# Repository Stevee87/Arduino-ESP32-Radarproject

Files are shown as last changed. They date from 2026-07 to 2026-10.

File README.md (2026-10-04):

# Arduino ESP32 mmWave Radar Project
-------------------------------------------------------------------------------------------------------
Safety & disclaimer

This is a hobby project, shared as-is for anyone who wants to build their own version.
A few things to know before you do:

LiPo batteries: incorrect wiring, reverse polarity, or physical damage to a
LiPo cell can cause fire. Double-check polarity yourself before powering anything
on, use a charging module rated for the cell you're using, and never leave a
charging LiPo unattended.
RF hardware: the RD-03D and any radio modules in this project operate
according to their respective regulatory approvals (e.g. CE) for their intended
region — verify this applies to your location before use.
No warranty: this repository (firmware, wiring diagrams, enclosures, and this
README) is provided without any warranty, express or implied. Verify every
connection yourself before applying power — don't assume the diagrams here are
free of mistakes.
Use at your own risk: building and operating this project is entirely your
own responsibility. The author assumes no liability for damage, injury, or loss
resulting from building or using this project.

If you spot an error in the docs, wiring, or code, please open an issue — corrections
are welcome.
-------------------------------------------------------------------------------------------------------

A wireless 24GHz mmWave motion tracking system. A standalone radar node reports detected
targets over Wi-Fi to a separate display unit — so the radar and the screen don't have to
be in the same place.

v22 v21

## How it works

The radar module talks to an Arduino GIGA R1 via a Wi-Fi hotspot using a Seeed XIAO
ESP32-S3 as the transmitter. Because the link is wireless, the radar node can be placed
anywhere as a standalone motion detector, independent of where the display sits.

## Features

- Multi-target tracking (up to 3 people simultaneously, RD-03D built-in algorithm)
- 8 m rated detection range (expect 5–7 m indoors)
- Live radar-style visualization on the GIGA Display Shield
- Distance-reactive tracker sound (passive piezo buzzer, tempo and pitch scale with
  the closest target's distance) — mute toggle built into the touchscreen
- LED battery level indicators on both battery packs
- Battery powered on both ends, USB-C rechargeable

## Known limitations

- The RD-03D is a **Doppler-based** radar — it only detects *moving* targets. People
  standing still are not detected.
- Works best stationary. It can detect people while the sensor itself is moving, but
  accuracy drops significantly.
- Can detect motion through thin doors/walls, but range is severely reduced — a
  consequence of 24GHz wave physics, not a firmware limitation.
- **Boot order matters**: always power on the GIGA R1 first and let it fully initialize
  before powering the radar node. Otherwise the Wi-Fi connection will not be established.

## Bill of materials

| Qty | Part |
|---|---|
| 1 | Arduino GIGA R1 |
| 1 | Arduino GIGA Display Shield |
| 1 | Seeed Studio XIAO ESP32-S3 |
| 1 | RD-03D radar module (Ai-Thinker) |
| 2 | Toggle switch |
| 2 | MT3608 step-up converter |
| 1 | 3.7V LiPo, 1160100 (≥5000mAh) — GIGA side |
| 1 | 3.7V LiPo, 602560 (~1300mAh) — radar side |
| 2 | BW4056 USB-C charging module |
| 1 | Passive piezo buzzer module (VCC/GND/Signal, tracker sound, GIGA side) |
| 2 | Mini Battery Level Indicator, 1S Li-ion — [ElectroPeak BAT-03-086](https://electropeak.com/mini-battery-level-indicator-1s-li-ion), one per LiPo |
| 4 | Magnets |
| — | Wires, M3 heat-set inserts, M3x10mm screws, 3D printer, glue, tape |

## Wiring

circuit diagram v2

**Power (GIGA side):** LiPo (5000mAh) → BW4056 charging module → toggle switch →
step-up converter set to 7–7.5V → GIGA `VIN`. Do not set it to 6V: that is the
bottom of the GIGA's 6–24V input range and the board browns out as the cell
discharges. Alternatively feed 5V into the GIGA's USB-C port from a 5V boost or
power-bank module and skip `VIN` altogether.

**Power (radar side):** LiPo (1300mAh) → BW4056 charging module → toggle switch →
XIAO `BAT+`/`BAT-` (on the back of the board), **directly**. A second branch from
the switched battery rail feeds the step-up converter set to 5V, which powers
**only the RD-03D**.

Never connect the 5V step-up output to `BAT+`: the BAT pads are the cell
terminals of the XIAO's 1S charger (4.2V maximum), and a cell behind a boost
converter cannot be charged by the XIAO. With the cell on the BAT pads the XIAO's
USB-C also charges it (100mA, slow); never charge through the BW4056 and the XIAO
at the same time.

### XIAO ESP32-S3 ↔ RD-03D (transmitter)

| RD-03D pin | XIAO pin | Notes |
|---|---|---|
| TX | D0 (GPIO1) | UART1 RX |
| RX | D1 (GPIO2) | UART1 TX |
| BAT+ | — | 3,7 V from the TP4056 |
| GND | GND | |

CAUTION: When charging the battery, set the POWER button to OFF. The same applies when the microcontroller is connected via USB-C. 

Baud rate: 256000. Do **not** use D6/D7 (GPIO43/44) — reserved for USB-Serial (UART0).

Antennas: neither the XIAO ESP32-S3 nor the GIGA R1 WiFi has an on-board antenna.
Plug in the u.FL antenna that ships with each board, and route the XIAO's away from
the LiPo and the magnets, or the Wi-Fi link will only work over a few metres.

### Wi-Fi link
### Arduino Giga R1 ↔ (receiver)
| | Value |
|---|---|
| Mode | GIGA R1 hosts an access point, XIAO connects as client |
| SSID | `RadarNet` |
| Password | `radar12345` |
| UDP port | 4210 |
| GIGA IP | 192.168.3.1 (default of the Arduino Mbed core; the sketch never sets an address and the XIAO uses the DHCP gateway, so nothing depends on this value) |

### Tracker sound (buzzer)

| Buzzer | GIGA R1 |
|---|---|
| VCC | 3V3 (GIGA pins are not 5V tolerant and many 3-pin buzzer modules pull the signal line up to VCC) |
| Signal (I/O) | D9 |
| GND | GND |

Must be a **passive** piezo buzzer, not active — an active buzzer has its own
oscillator and only turns on/off, ignoring the frequency argument the code sends it.

Behavior: silent when no target is detected. Once a target appears, it emits short
(70ms) pings whose repeat rate and pitch both scale with the distance to the closest
detected target — pings speed up and rise in pitch as someone gets closer (900ms /
700Hz at ~8m down to 120ms / 1800Hz at ≤30cm). A mute toggle button is drawn directly
on the touchscreen; tapping it silences the buzzer without affecting the radar
visualization.

### Battery level indicators

Two [ElectroPeak Mini Battery Level Indicator (1S Li-ion)](https://electropeak.com/mini-battery-level-indicator-1s-li-ion)
boards, one per LiPo pack. These are standalone analog modules (built-in comparator,
±1% accuracy) — no microcontroller pin or firmware involved. Wire each board directly
across its own battery's `+`/`-` terminals (in parallel with the existing BW4056 /
step-up wiring, not in series):

| Indicator LEDs lit | Charge level |
|---|---|
| 4 | 100% |
| 3 | 75% |
| 2 | 50% |
| 1 | 25% |

Board size is tiny (5 × 9.5mm) — tuck it wherever it fits in the enclosure near the
battery leads.

## Firmware

Open `Firmware/rd03d_xiao_s3_transmitter/rd03d_xiao_s3_transmitter.ino` and flash it to
the XIAO ESP32-S3, then open `Firmware/rd03d_giga_receiver/rd03d_giga_receiver.ino` and
flash it to the GIGA R1 — both via Arduino IDE.

**Board packages:**
- `esp32` by Espressif (3.x) — board "XIAO_ESP32S3", *USB CDC On Boot: Enabled*
- `Arduino Mbed OS GIGA Boards` (4.x) — board "Arduino GIGA R1 WiFi". If the GIGA has never
  run Wi-Fi, flash *File → Examples → STM32H747_System → WiFiFirmwareUpdater* once first.

**Required libraries:**
- `Arduino_GigaDisplay_GFX` (GIGA — display rendering; depends on `Adafruit GFX Library`)
- `Arduino_GigaDisplayTouch` (GIGA — touch input)
- `WiFi` / `WiFiUdp` (both boards, built into their respective cores)

## Enclosures

Four 3D-printable parts are included in `CAD files/` (binary STL; bounding boxes
measured from the files):

| File | Bounding box (mm) | Part |
|---|---|---|
| `CAD files/body display.stl` | 34 × 105 × 113 | display body (GIGA + shield + 1160100 LiPo) |
| `CAD files/top display.stl` | 8 × 85 × 111 | display lid |
| `CAD files/top radarmodule.stl` | 47 × 31 × 87 | radar node body |
| `CAD files/bottom radarmodule.stl` | 47 × 6 × 67 | radar node base plate |

## Build photos (older ones, without the battery indicator and buzzer)

building pictures

## License

MIT — see [LICENSE](LICENSE).

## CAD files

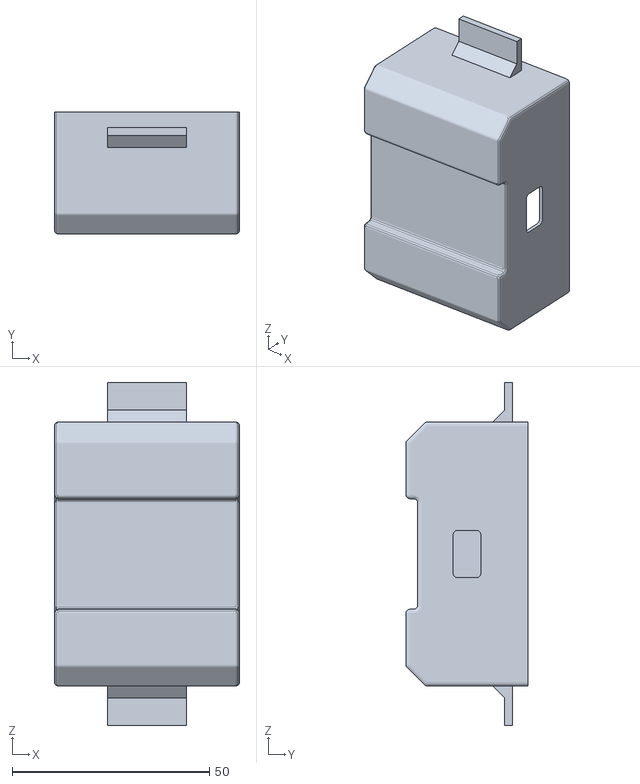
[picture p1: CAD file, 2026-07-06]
CAD files/top radarmodule.stl
47.0 x 31.0 x 87.0

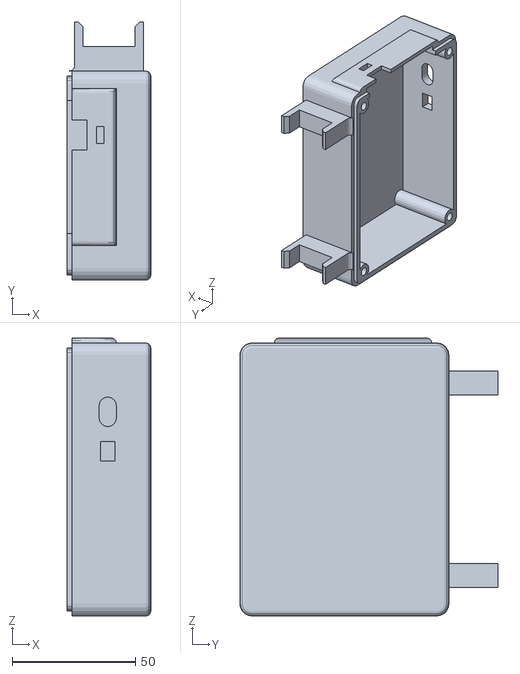
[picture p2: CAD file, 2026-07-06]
CAD files/body display.stl
34.0 x 105.0 x 113.0

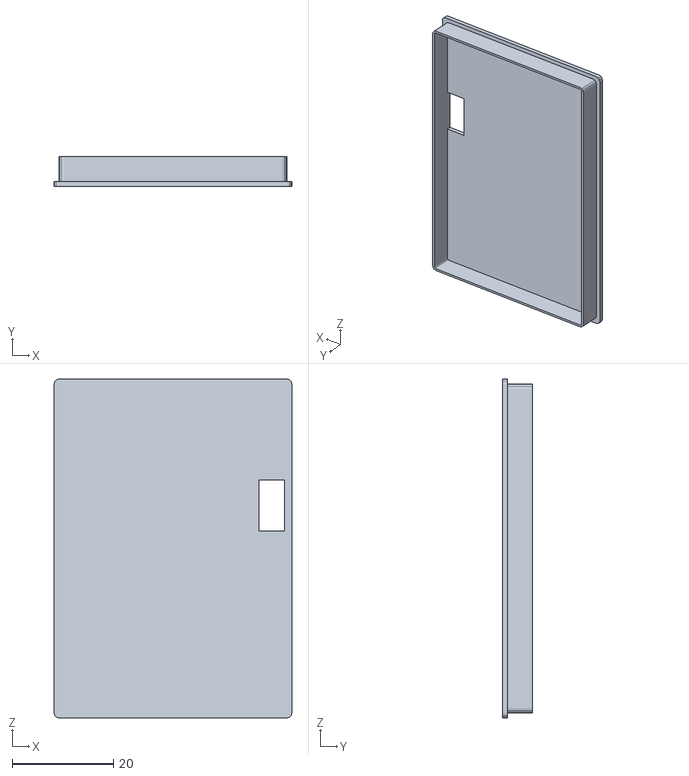
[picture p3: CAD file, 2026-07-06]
CAD files/bottom radarmodule.stl
47.0 x 6.00 x 67.0

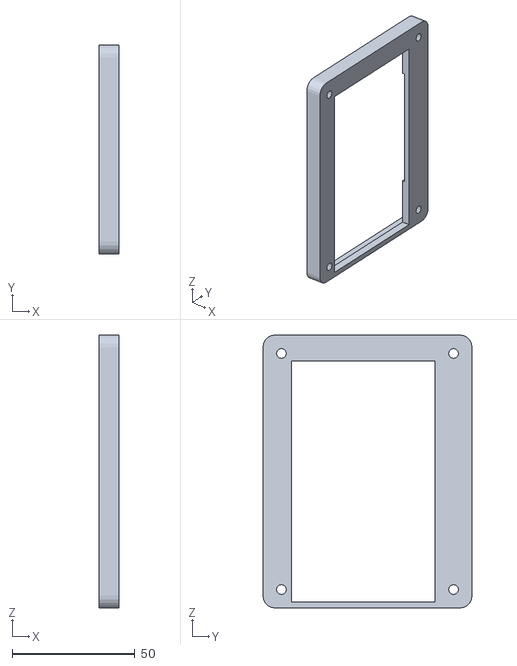
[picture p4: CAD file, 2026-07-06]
CAD files/top display.stl
8.00 x 85.0 x 111.0

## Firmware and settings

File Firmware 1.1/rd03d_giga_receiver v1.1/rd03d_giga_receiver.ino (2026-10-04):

/*
 * RD-03D Radar Display — Arduino Giga R1
 * Empfängt UDP-Pakete vom Single-Sensor-Sender und zeigt bis zu 3 Targets
 * auf dem Display (ein RD-03D, 120° Sichtfeld).
 *
 * NETZWERK:
 *   Giga R1 ist Hotspot: SSID "RadarNet", PW "radar12345"
 *   Eigene IP: 192.168.3.1 (Standard des Arduino-Mbed-Cores; der XIAO nutzt die Gateway-IP)
 *   UDP Port: 4210
 */

#include <WiFi.h>
#include <WiFiUdp.h>
#include "Arduino_GigaDisplay_GFX.h"
#include "Arduino_GigaDisplayTouch.h"

// ── Netzwerk ──
const char*    AP_SSID = "RadarNet";
const char*    AP_PASS = "radar12345";
const uint16_t UDP_PORT = 4210;

// ── Display ──
#define SCREEN_W    800
#define SCREEN_H    480
#define RADAR_CX    400
#define RADAR_CY    480
#define RADAR_R     440
#define MAX_DIST_MM 8000.0f
#define SECTOR_HALF 60.0f
#define MAX_TARGETS 3
#define MOVE_THRESH_MM 15.0f

// ── Ein Sensor, 120° FOV, zentriert auf die Gerätefront (0°) ──
#define NUM_SECTORS 1
const float SECTOR_CENTERS[NUM_SECTORS] = {0.0f};

// ── Buzzer (Tracker-Sound) ──
#define BUZZER_PIN     9      // passiver Piezo-Buzzer, KEIN aktiver Buzzer!

// Jeder Ping besteht aus 2 Stufen: kurzer heller "Klick" (Attack) direkt
// gefolgt vom eigentlichen Ton — kommt dem hellen, sonarartigen Charakter
// des Vorbilds näher als ein einzelner flacher Ton.
// Jeder Ping ist ein kurzer 3-stufiger AUFWÄRTS-Sweep (tief -> mittel ->
// Zielfrequenz), statt eines einzelnen flachen Tons — klingt nach einem
// ansteigenden Sonar-Ping statt einem Klick.
const uint16_t PING_STAGE1_MS = 26;
const uint16_t PING_STAGE2_MS = 24;
const uint16_t PING_STAGE3_MS = 30;
#define BEEP_DUR_MS  (PING_STAGE1_MS + PING_STAGE2_MS + PING_STAGE3_MS)   // Gesamtlänge eines Pings

const float    BEEP_DIST_MIN      = 300.0f;   // mm — ab hier schnellster/höchster Ping
const float    BEEP_DIST_MAX      = 8000.0f;  // mm — ab hier langsamster/tiefster Ping
const uint16_t BEEP_INTERVAL_MIN  = 120;      // ms Pause zwischen Pings bei minimaler Distanz
const uint16_t BEEP_INTERVAL_MAX  = 900;      // ms Pause zwischen Pings bei maximaler Distanz
const uint16_t BEEP_FREQ_MIN      = 700;      // Hz — Tonhöhe weit weg (Kompromiss: lauter, aber unterhalb des schrillen Bereichs)
const uint16_t BEEP_FREQ_MAX      = 1400;     // Hz — Tonhöhe nah dran

// ── Mute-Button (Touch) ──
#define BTN_X 660
#define BTN_Y 400
#define BTN_W 130
#define BTN_H 40
bool buzzerMuted = false;

// ── Range-HUD-Position (Basis der Radar-Kuppel, überdeckt Ursprung) ──
#define RANGE_HUD_W 140
#define RANGE_HUD_H 40
#define RANGE_HUD_X (RADAR_CX - RANGE_HUD_W/2)
#define RANGE_HUD_Y (RADAR_CY - RANGE_HUD_H)

// ── Farben ──
#define C_BG    0x0000
#define C_GREEN 0x07E0
#define C_GDIM  0x02E0
#define C_RED   0xF800
#define C_AMBER 0xFD20
#define C_CYAN  0x07FF
#define C_WHITE 0xFFFF

GigaDisplay_GFX          display;
Arduino_GigaDisplayTouch touch;
WiFiUDP                  udp;

struct Target {
  int16_t x;
  int16_t y;
  int16_t spd;
  uint8_t valid;
};

struct __attribute__((packed)) UdpPacket {
  uint32_t magic;
  uint32_t frameCount;
  Target   targets[MAX_TARGETS];
};

struct DisplayTarget {
  float x, y, spd;
  bool  valid;
};

struct DotState {
  int16_t cx, cy, bx, by, bw, bh;
  bool active;
};

DisplayTarget targets[MAX_TARGETS];
DisplayTarget lastDrawn[MAX_TARGETS];
DotState      dots[MAX_TARGETS];

// ── Ghost-Filter: Ziel, das sich 2s lang nicht (spürbar) bewegt, gilt als ──
// Störung/Geisterziel (der RD-03D erkennt stehende Personen ohnehin nicht
// zuverlässig — ein "Ziel", das sich gar nicht bewegt, ist verdächtig) und
// wird ausgeblendet, bis es sich wieder über MOVE_THRESH_MM hinaus bewegt.
DisplayTarget prevRaw[MAX_TARGETS];       // Ground-Truth letzte Rohposition
uint32_t      stillSinceMs[MAX_TARGETS];  // Zeitpunkt der letzten echten Bewegung
const uint32_t STILL_TIMEOUT_MS = 2000;

uint32_t frameCount = 0;
uint32_t lastPacketMs = 0;
bool     txConnected = false;

// Buzzer-Status
uint32_t lastBeepMs   = 0;
bool     beepActive   = false;
uint8_t  chirpStage      = 0;   // 0=idle, 1/2/3=Sweep-Stufen (tief->mittel->Ziel)
uint32_t chirpStageStart = 0;
uint16_t chirpMainFreq   = 0;

// Hintergrund-Puls: läuft konstant, solange das Gerät an ist — unabhängig
// davon, ob ein Ziel erkannt wird. Signalisiert "Radar läuft/scannt".
const uint16_t PULSE_FREQ        = 300;   // Hz, Original-Wert
const uint16_t PULSE_DUR_MS      = 40;    // kurz, damit es nicht aufdringlich wird
const uint32_t PULSE_INTERVAL_MS = 1800;  // Pause zwischen zwei Pulsen
uint32_t lastPulseMs  = 0;
bool     pulseActive  = false;
uint32_t pulseStartMs = 0;

// ── UDP empfangen ──
// Wartende Datagramme abholen und das letzte gültige Paket anzeigen.
void receiveUdp() {
  static uint32_t lastDebug = 0;
  static uint32_t rxCount   = 0;
  UdpPacket pkt = {};
  bool gotPacket = false;
  int sz;
  while ((sz = udp.parsePacket()) > 0) {
    if (sz < (int)sizeof(UdpPacket)) continue;
    UdpPacket tmp = {};
    if (udp.read((uint8_t*)&tmp, sizeof(tmp)) != (int)sizeof(tmp)) continue;
    if (tmp.magic != 0xD03DA7A) continue;
    pkt = tmp;
    gotPacket = true;
    rxCount++;
  }
  if (millis() - lastDebug > 2000) {
    lastDebug = millis();
    Serial.print("UDP Pakete gesamt="); Serial.println(rxCount);
  }
  if (!gotPacket) return;

  frameCount = pkt.frameCount;
  lastPacketMs = millis();
  txConnected = true;

  for (int i = 0; i < MAX_TARGETS; i++) {
    if (pkt.targets[i].valid) {
      targets[i].x     = (float)pkt.targets[i].x;
      targets[i].y     = (float)pkt.targets[i].y;
      targets[i].spd   = (float)abs(pkt.targets[i].spd);
      targets[i].valid = true;
    } else {
      targets[i].valid = false;
    }
  }
}

// ── Maßstab ──
float distToR(float d) {
  if (d <= 0)       return 0;
  if (d <= 2000.0f) return (d/2000.0f)                          * 0.50f * RADAR_R;
  if (d <= 4000.0f) return (0.50f+(d-2000.0f)/2000.0f*0.25f)   * RADAR_R;
  if (d <= 6000.0f) return (0.75f+(d-4000.0f)/2000.0f*0.15f)   * RADAR_R;
  return              (0.90f+(d-6000.0f)/2000.0f*0.10f)         * RADAR_R;
}

void targetToPixel(float x, float y, int16_t &px, int16_t &py) {
  float dist  = sqrtf(x*x + y*y);
  float angle = atan2f(x, y) * 180.0f / PI;
  float r     = distToR(dist);
  float rad   = (angle - 90.0f) * PI / 180.0f;
  px = RADAR_CX + (int16_t)(r * cosf(rad));
  py = RADAR_CY + (int16_t)(r * sinf(rad));
}

// ── Hintergrund-Region neu zeichnen ──
void redrawBg(int16_t rx1, int16_t ry1, int16_t rw, int16_t rh) {
  int16_t rx2 = rx1+rw-1, ry2 = ry1+rh-1;
  if (rx1<0) rx1=0; if (ry1<0) ry1=0;
  if (rx2>=SCREEN_W) rx2=SCREEN_W-1;
  if (ry2>=SCREEN_H) ry2=SCREEN_H-1;
  if (rx1>rx2||ry1>ry2) return;
  display.fillRect(rx1,ry1,rx2-rx1+1,ry2-ry1+1,C_BG);
  for (int s=0; s<NUM_SECTORS; s++) {
    float c = SECTOR_CENTERS[s];
    float rd[]={1000,2000,3000,4000,5000,6000,7000,8000};
    uint16_t rc[]={C_GREEN,0x00C0,0x00C0,C_GDIM,0x00C0,0x00C0,0x00C0,C_GREEN};
    for (int ri=0; ri<8; ri++) {
      float r=distToR(rd[ri]);
      for (float a=c-SECTOR_HALF; a<=c+SECTOR_HALF; a+=0.5f) {
        float rad=(a-90.0f)*PI/180.0f;
        int16_t px=RADAR_CX+(int16_t)(r*cosf(rad)), py=RADAR_CY+(int16_t)(r*sinf(rad));
        if (px>=rx1&&px<=rx2&&py>=ry1&&py<=ry2) display.drawPixel(px,py,rc[ri]);
      }
    }
    int degs[]={-60,-30,0,30,60};
    for (int i=0; i<5; i++) {
      float rad=(c+degs[i]-90.0f)*PI/180.0f;
      for (float r=0; r<=RADAR_R; r+=1.5f) {
        int16_t px=RADAR_CX+(int16_t)(r*cosf(rad)), py=RADAR_CY+(int16_t)(r*sinf(rad));
        if (px>=rx1&&px<=rx2&&py>=ry1&&py<=ry2) display.drawPixel(px,py,degs[i]==0?C_GDIM:0x0200);
      }
    }
  }
  if (RADAR_CX>=rx1&&RADAR_CX<=rx2&&RADAR_CY>=ry1&&RADAR_CY<=ry2) {
    display.fillCircle(RADAR_CX,RADAR_CY,5,C_GREEN);
    display.drawCircle(RADAR_CX,RADAR_CY,9,C_GDIM);
  }
}

// ── Aktive Dots neu zeichnen, die von einer Region betroffen sein könnten ──
// (z.B. nachdem redrawBg() über sie drübergemalt hat)
void redrawDotsInRegion(int16_t rx1, int16_t ry1, int16_t rw, int16_t rh) {
  int16_t rx2 = rx1 + rw - 1, ry2 = ry1 + rh - 1;
  for (int i = 0; i < MAX_TARGETS; i++) {
    if (!dots[i].active) continue;
    if (dots[i].bx <= rx2 && dots[i].bx + dots[i].bw - 1 >= rx1 &&
        dots[i].by <= ry2 && dots[i].by + dots[i].bh - 1 >= ry1) {
      drawDot(i);
    }
  }
}

// ── Sichtbarer Sonar-Ping: ein Ring, der vom Ursprung nach außen läuft ──
void drawPingRing(float r, uint16_t color) {
  for (int s = 0; s < NUM_SECTORS; s++) {
    float c = SECTOR_CENTERS[s];
    for (float a = c - SECTOR_HALF; a <= c + SECTOR_HALF; a += 0.5f) {
      float rad = (a - 90.0f) * PI / 180.0f;
      int16_t px = RADAR_CX + (int16_t)(r * cosf(rad));
      int16_t py = RADAR_CY + (int16_t)(r * sinf(rad));
      if (px < 0 || px >= SCREEN_W || py < 0 || py >= SCREEN_H) continue;
      // Range-HUD-Bar an der Basis aussparen, sonst überschreibt der
      // durchlaufende Ping kurzzeitig die Zahl
      if (px >= RANGE_HUD_X && px <= RANGE_HUD_X + RANGE_HUD_W &&
          py >= RANGE_HUD_Y && py <= RANGE_HUD_Y + RANGE_HUD_H) continue;
      display.drawPixel(px, py, color);
    }
  }
}

// Hintergrundfarbe, die an Radius r "eigentlich" stehen würde (feste
// Range-Ring-Farbe falls Treffer, sonst normale BG-Farbe) — für das
// günstige Zurückschreiben beim Löschen des Ping-Rings.
uint16_t bgColorAtRadius(float r) {
  float rangeMm[]  = {1000,2000,3000,4000,5000,6000,7000,8000};
  uint16_t rangeCol[] = {C_GREEN,0x00C0,0x00C0,C_GDIM,0x00C0,0x00C0,0x00C0,C_GREEN};
  for (int k = 0; k < 8; k++) {
    if (fabsf(distToR(rangeMm[k]) - r) < 1.0f) return rangeCol[k];
  }
  return C_BG;
}

// Bounding-Box eines Rings bei Radius r über alle Sektoren hinweg — NUR
// zur groben Prüfung, ob ein Dot vom Ring gekreuzt wird, NICHT für einen
// vollflächigen Redraw (der wäre bei einem 120°-Bogen riesig und würde
// weit entfernte UI-Elemente wie Info-Box/Button mit überschreiben).
void ringBoundingBox(float r, int16_t &bx1, int16_t &by1, int16_t &bx2, int16_t &by2) {
  float minA = SECTOR_CENTERS[0] - SECTOR_HALF;
  float maxA = SECTOR_CENTERS[NUM_SECTORS-1] + SECTOR_HALF;
  bx1 = 32000; by1 = 32000; bx2 = -32000; by2 = -32000;
  for (float a = minA; a <= maxA; a += 2.0f) {
    float rad = (a - 90.0f) * PI / 180.0f;
    int16_t px = RADAR_CX + (int16_t)(r * cosf(rad));
    int16_t py = RADAR_CY + (int16_t)(r * sinf(rad));
    if (px < bx1) bx1 = px; if (px > bx2) bx2 = px;
    if (py < by1) by1 = py; if (py > by2) by2 = py;
  }
  bx1 -= 2; by1 -= 2; bx2 += 2; by2 += 2;
}

// Sweep-Dauer bewusst etwas kürzer als PULSE_INTERVAL_MS (Puls löst den
// Ring aus, siehe triggerPing() in updateBackgroundPulse) — Ring läuft
// exakt im Takt des Sounds, kein eigener Pause-Timer mehr nötig.
const float    PING_SPEED_PX_MS = 440.0f / (PULSE_INTERVAL_MS - 200.0f);
const uint32_t PING_FRAME_MS    = 40;                // ~25 FPS für die Animation

float    pingRadius        = 0;
float    pingPrevRadius    = -1;
bool     pingRunning        = false;
uint32_t lastPingFrameMs   = 0;

// Wird vom Sound-Puls aufgerufen — startet den Ring exakt im gleichen Moment
void triggerPing() {
  pingRadius   = 0;
  pingRunning  = true;
}

void updatePing() {
  uint32_t now = millis();
  if (now - lastPingFrameMs < PING_FRAME_MS) return;
  float dt = (float)(now - lastPingFrameMs);
  lastPingFrameMs = now;

  // Alten Ring löschen: NUR die exakt gleichen Pixel zurückschreiben, die
  // gezeichnet wurden (billig, ~240 Punkte) statt eine teure
  // Bounding-Box-Fläche über redrawBg() neu zu zeichnen (das kostet pro
  // Aufruf zehntausende Iterationen und malt dabei über Info-Box/Button).
  if (pingPrevRadius >= 0) {
    drawPingRing(pingPrevRadius, bgColorAtRadius(pingPrevRadius));
    int16_t bx1, by1, bx2, by2;
    ringBoundingBox(pingPrevRadius, bx1, by1, bx2, by2);
    redrawDotsInRegion(bx1, by1, bx2 - bx1 + 1, by2 - by1 + 1);
    pingPrevRadius = -1;
  }

  if (!pingRunning) return;

  drawPingRing(pingRadius, C_GREEN);
  pingPrevRadius = pingRadius;
  pingRadius += PING_SPEED_PX_MS * dt;

  if (pingRadius > RADAR_R) {
    pingRunning = false;
  }
}

// ── Hintergrund initial ──
void drawBackground() {
  display.fillScreen(C_BG);
  for (int s=0; s<NUM_SECTORS; s++) {
    float c = SECTOR_CENTERS[s];

    float rd[]={1000,2000,3000,4000,5000,6000,7000,8000};
    uint16_t rc[]={C_GREEN,0x00C0,0x00C0,C_GDIM,0x00C0,0x00C0,0x00C0,C_GREEN};
    for (int ri=0; ri<8; ri++) {
      float r=distToR(rd[ri]);
      for (float a=c-SECTOR_HALF; a<=c+SECTOR_HALF; a+=0.5f) {
        float rad=(a-90.0f)*PI/180.0f;
        int16_t px=RADAR_CX+(int16_t)(r*cosf(rad)), py=RADAR_CY+(int16_t)(r*sinf(rad));
        if (px>=0&&px<SCREEN_W&&py>=0&&py<SCREEN_H) display.drawPixel(px,py,rc[ri]);
      }
      // Distanz-Label nur an der äußeren rechten Kante von Sektor 0 setzen,
      // sonst würden sich die Labels beider Sektoren an der gemeinsamen
      // Nahtstelle (60°) überlappen.
      if (s==0) {
        display.setTextColor(ri==0||ri==7?C_GREEN:0x0380); display.setTextSize(1);
        char buf[8]; sprintf(buf,"%.0fm",rd[ri]/1000.0f);
        float rR=(c+SECTOR_HALF+6.0f-90.0f)*PI/180.0f;  // etwas außerhalb der Randlinie, nicht mehr drauf
        int16_t lx=RADAR_CX+(int16_t)((r+4)*cosf(rR))+4, ly=RADAR_CY+(int16_t)((r+4)*sinf(rR))-4;
        if (lx>=0&&lx<SCREEN_W&&ly>=0&&ly<SCREEN_H) { display.setCursor(lx,ly); display.print(buf); }
      }
    }

    float radL=(c-SECTOR_HALF-90.0f)*PI/180.0f, radR=(c+SECTOR_HALF-90.0f)*PI/180.0f;
    for (int off=-1; off<=1; off++) {
      display.drawLine(RADAR_CX+off,RADAR_CY,RADAR_CX+off+(int16_t)(RADAR_R*cosf(radL)),RADAR_CY+(int16_t)(RADAR_R*sinf(radL)),C_GREEN);
      display.drawLine(RADAR_CX+off,RADAR_CY,RADAR_CX+off+(int16_t)(RADAR_R*cosf(radR)),RADAR_CY+(int16_t)(RADAR_R*sinf(radR)),C_GREEN);
    }

    int degs[]={-60,-30,0,30,60};
    for (int i=0; i<5; i++) {
      float rad=(c+degs[i]-90.0f)*PI/180.0f;
      display.drawLine(RADAR_CX,RADAR_CY,RADAR_CX+(int16_t)(RADAR_R*cosf(rad)),RADAR_CY+(int16_t)(RADAR_R*sinf(rad)),degs[i]==0?C_GDIM:0x0260);
      char buf[5]; sprintf(buf,"%d",(int)(c+degs[i]));
      float lr=RADAR_R+14.0f;
      int16_t lx=RADAR_CX+(int16_t)(lr*cosf(rad))-6, ly=RADAR_CY+(int16_t)(lr*sinf(rad))-4;
      if (lx>=0&&lx<SCREEN_W&&ly>=0) { display.setTextColor(degs[i]==0?C_GREEN:0x0380); display.setTextSize(1); display.setCursor(lx,ly); display.print(buf); }
    }
  }
  display.fillCircle(RADAR_CX,RADAR_CY,5,C_GREEN);
  display.drawCircle(RADAR_CX,RADAR_CY,9,C_GDIM);
  // Info-Box
  display.fillRect(670,0,130,70,0x0820);
  display.setTextColor(C_GDIM); display.setTextSize(1);
  display.setCursor(675, 4); display.print("RD-03D 24GHz");
  display.setCursor(675,14); display.print("3T 8m 120deg");
  display.setCursor(675,24); display.print("AP: RadarNet");
}

// 3 Targets vom einzigen Sensor
static const uint16_t DOT_COLS[MAX_TARGETS] = {C_RED, C_AMBER, C_CYAN};

void eraseDot(int i) {
  if (!dots[i].active) return;
  redrawBg(dots[i].bx, dots[i].by, dots[i].bw, dots[i].bh);
  dots[i].active = false;
}

void drawDot(int i) {
  int16_t tx, ty;
  targetToPixel(targets[i].x, targets[i].y, tx, ty);
  uint16_t col = DOT_COLS[i];
  int16_t bx=tx-22, by=ty-22, bw=44, bh=44;
  display.drawCircle(tx,ty,18,col);
  display.drawCircle(tx,ty,11,col);
  display.fillCircle(tx,ty, 5,col);
  dots[i]      = {tx,ty,bx,by,bw,bh,true};
  lastDrawn[i] = targets[i];
}

bool staleNow[MAX_TARGETS];

// ── Distanz-Labels fest am Ursprung statt am beweglichen Punkt ──
// Fester, umrandeter Kasten unter dem Mute-Button — nicht mehr am
// beweglichen Ursprung, sondern in der gleichen UI-Spalte wie Info-Box
// und Button. Malt sich komplett selbst neu (eigener Hintergrund-Fill),
// braucht kein redrawBg() und kann daher auch nichts anderes überschreiben.
#define TGT_BOX_X   10
#define TGT_BOX_Y   400
#define TGT_BOX_W   130
#define TGT_BOX_LINE_H 14
#define TGT_BOX_H   (MAX_TARGETS * TGT_BOX_LINE_H + 16)
const uint32_t TGT_BOX_INTERVAL_MS = 150;
uint32_t lastTgtBoxMs = 0;

void drawTargetBox() {
  display.fillRect(TGT_BOX_X, TGT_BOX_Y, TGT_BOX_W, TGT_BOX_H, 0x0820);
  display.drawRect(TGT_BOX_X, TGT_BOX_Y, TGT_BOX_W, TGT_BOX_H, C_GDIM);
  display.setTextColor(C_GDIM); display.setTextSize(1);
  display.setCursor(TGT_BOX_X + 6, TGT_BOX_Y + 4);
  display.print("TARGETS");

  display.setTextSize(1);
  int line = 0;
  for (int i = 0; i < MAX_TARGETS; i++) {
    if (!targets[i].valid || staleNow[i]) continue;
    float dist = sqrtf(targets[i].x*targets[i].x + targets[i].y*targets[i].y);
    char buf[20];
    if (targets[i].spd > 2.0f) sprintf(buf, "T%d %.2fm %dcm/s", i+1, dist/1000.0f, (int)targets[i].spd);
    else                       sprintf(buf, "T%d %.2fm", i+1, dist/1000.0f);
    display.setTextColor(DOT_COLS[i]);
    display.setCursor(TGT_BOX_X + 6, TGT_BOX_Y + 16 + line * TGT_BOX_LINE_H);
    display.print(buf);
    line++;
  }
}

void updateTargetBox() {
  if (millis() - lastTgtBoxMs < TGT_BOX_INTERVAL_MS) return;
  lastTgtBoxMs = millis();
  drawTargetBox();
}

// ── Großer Range-Readout an der Basis der Radar-Kuppel (Ursprungspunkt) ──
// Referenz: Tracker-UI mit großer Zahl direkt unter der Scope-Grafik.
// Bei unserem Layout sitzt der Ursprung am unteren Bildschirmrand, daher
// wird die Bar dort platziert statt "unter" dem Bogen — überdeckt den
// Ursprungsmarker bewusst, genau wie im Referenzbild der Fokuspunkt der
// Kuppel durch die Zahl ersetzt wird.
const uint32_t RANGE_HUD_INTERVAL_MS = 150;
uint32_t lastRangeHudMs = 0;

void drawRangeHud() {
  display.fillRect(RANGE_HUD_X, RANGE_HUD_Y, RANGE_HUD_W, RANGE_HUD_H, 0x0000);
  display.drawRect(RANGE_HUD_X, RANGE_HUD_Y, RANGE_HUD_W, RANGE_HUD_H, C_GDIM);

  float dist = closestTargetDistMm();
  display.setTextSize(3);
  char buf[10];
  if (dist >= 0) {
    display.setTextColor(C_RED);
    sprintf(buf, "%.2fm", dist/1000.0f);
  } else {
    display.setTextColor(C_GDIM);
    sprintf(buf, "---");
  }
  int16_t textW = strlen(buf) * 18;  // grobe Breitenschätzung bei textSize(3)
  display.setCursor(RADAR_CX - textW/2, RANGE_HUD_Y + (RANGE_HUD_H - 24) / 2);
  display.print(buf);

  // Ziel-Dots, die von der Bar überdeckt wurden, wiederherstellen
  redrawDotsInRegion(RANGE_HUD_X, RANGE_HUD_Y, RANGE_HUD_W, RANGE_HUD_H);
}

void updateRangeHud() {
  if (millis() - lastRangeHudMs < RANGE_HUD_INTERVAL_MS) return;
  lastRangeHudMs = millis();
  drawRangeHud();
}

void updateDots() {
  uint32_t now = millis();
  for (int i = 0; i < MAX_TARGETS; i++) {
    staleNow[i] = false;
    if (!targets[i].valid) {
      stillSinceMs[i] = 0;
      prevRaw[i].valid = false;
      if (dots[i].active) eraseDot(i);
      continue;
    }

    // Echte Bewegung seit dem letzten Frame? (Ground-Truth, unabhängig vom
    // Rendering — läuft auch weiter, wenn der Punkt gerade ausgeblendet ist)
    bool movedRaw = !prevRaw[i].valid ||
                    fabsf(targets[i].x - prevRaw[i].x) > MOVE_THRESH_MM ||
                    fabsf(targets[i].y - prevRaw[i].y) > MOVE_THRESH_MM;
    if (movedRaw) stillSinceMs[i] = now;
    prevRaw[i] = targets[i];

    bool stale = (now - stillSinceMs[i]) > STILL_TIMEOUT_MS;
    staleNow[i] = stale;
    if (stale) {
      if (dots[i].active) eraseDot(i);
      continue;  // ausgeblendet, Tracking läuft im Hintergrund weiter
    }

    bool moved = fabsf(targets[i].x - lastDrawn[i].x) > MOVE_THRESH_MM ||
                 fabsf(targets[i].y - lastDrawn[i].y) > MOVE_THRESH_MM;
    if (dots[i].active && !moved) continue;
    if (dots[i].active) eraseDot(i);
    drawDot(i);
  }

  // Info-Box aktualisieren (nur noch Verbindungsstatus — Zielanzahl/Distanz
  // stehen jetzt in der TARGETS-Box und im Range-HUD, keine Duplikate mehr)
  display.fillRect(671,34,128,36,0x0820);

  // Verbindungsstatus zum XIAO (Transmitter)
  bool alive = (millis() - lastPacketMs) < 3000;
  display.setTextColor(alive ? C_GREEN : C_RED); display.setTextSize(1);
  display.setCursor(675,36);
  display.print(alive ? "TX: OK  " : "TX: ---  ");
  char fb[16]; snprintf(fb, sizeof(fb), "fr:%lu", (unsigned long)frameCount);
  display.print(fb);
}

uint32_t lastUptimeMs = 0;
void updateUptime() {
  if (millis()-lastUptimeMs < 1000) return;
  lastUptimeMs = millis();
  // Verbindungsverlust: alle Dots löschen
  if ((millis() - lastPacketMs) > 3000 && txConnected) {
    for (int i=0; i<MAX_TARGETS; i++) {
      targets[i].valid = false;
      if (dots[i].active) eraseDot(i);
    }
  }
}

// ── Periodischer Voll-Redraw gegen "Schatten-Streifen" ──
// Die regionalen Teil-Redraws (redrawBg beim Dot-Löschen) summieren über
// Zeit kleine Rundungsdifferenzen zu sichtbaren Artefakten. Ein kompletter
// Neuzeichnen-Durchlauf alle 10s beseitigt das zuverlässig.
uint32_t lastBgRefreshMs = 0;
const uint32_t BG_REFRESH_INTERVAL_MS = 10000;

void refreshBackground() {
  drawBackground();
  drawMuteButton();
  for (int i = 0; i < MAX_TARGETS; i++) {
    dots[i].active = false;
    if (targets[i].valid) drawDot(i);
  }
  drawTargetBox();
  drawRangeHud();
  pingPrevRadius = -1;  // Ping-Ring-Status zurücksetzen, Bildschirm ist frisch
}

// ── Tracker-Sound ──

// Entfernung des nächstgelegenen validen Targets in mm, -1 wenn keins
float closestTargetDistMm() {
  float best = -1.0f;
  for (int i = 0; i < MAX_TARGETS; i++) {
    if (!targets[i].valid || staleNow[i]) continue;
    float d = sqrtf(targets[i].x * targets[i].x + targets[i].y * targets[i].y);
    if (best < 0 || d < best) best = d;
  }
  return best;
}
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
void loop() {
  receiveUdp();
  updateDots();
  updateTargetBox();
  updateRangeHud();
  updatePing();
  updateUptime();
  updateTrackerSound();
  updateBackgroundPulse();
  checkTouch();

  if (millis() - lastBgRefreshMs >= BG_REFRESH_INTERVAL_MS) {
    lastBgRefreshMs = millis();
    refreshBackground();
  }
}

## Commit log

2026-07-01 Update README with radar range details
    Added range information for the radar device.
2026-07-02 Revise README with project details and instructions
    Expanded project details, added features, limitations, and wiring instructions.
2026-07-06 Clarify build photos section title
    Updated section title for build photos to clarify that they are older versions without the battery indicator and buzzer.
2026-07-06 Clarify step-up converter model in README
    Updated note regarding step-up converter model in BOM.
2026-10-03 Fix WiFiUdp.h include name so the GIGA receiver builds on Linux
    The Arduino Mbed OS GIGA core ships the header as WiFiUdp.h. The include
    spelled WiFiUDP.h only resolves on case-insensitive file systems (Windows,
    macOS); on Linux the sketch fails with "WiFiUDP.h: No such file or directory".
    Claude-Session: https://claude.ai/code/session_01TGbEMWcJoFY7rARJoCEYFt
    [rd03d_giga_receiver.ino]
2026-10-03 README: correct power wiring, antennas, paths, IP, enclosure list
    Documentation fixes found while building from these instructions:
    * Radar node power: the 5V step-up output was routed into the XIAO's
    BAT+/BAT- pads, which are the 1S charger's cell terminals (4.2V max), and
    the text also expected the XIAO to charge that cell over USB, which cannot
    work through a boost converter. The cell now sits on the BAT pads directly
    and the step-up feeds only the RD-03D.
    * GIGA power: 6V is the minimum of the 6-24V VIN range and browns out as
    the cell sags; recommend 7-7.5V or 5V into USB-C.
    * RD-03D VCC comes from the step-up, not the XIAO's 5V pin (USB-only).
    * Both boards need their u.FL a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
2026-10-03 XIAO transmitter: non-blocking Wi-Fi and radar setup, clustering speed fix
    * connectWiFi() blocked for up to 20 s and then called ESP.restart(). With
    the GIGA off or out of range the XIAO sat in a reboot loop and read no radar
    at all. Connection is now started in the background, checked once a second
    and retried every 10 s; readRadar() keeps running and sending resumes as
    soon as the link is back. The UDP socket is opened on the first connection.
    * sendMultiTargetCmd() spent ~650 ms in delay() every 60 s, freezing all
    targets for close to a second each minute. It is now a four-step sequence
    advanced from loop() every 200 ms; radar bytes arriving during the
    configuration (comman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
2026-10-03 GIGA receiver: check AP start, drain UDP queue, fix overflow and labels
    * WiFi.beginAP() return value was ignored. When the Wi-Fi firmware is missing
    from the QSPI flash the AP silently fails, the screen shows IP 0.0.0.0 and the
    XIAO never finds a network, which looks exactly like the "boot order matters"
    limitation in the README. Now the status is printed, shown in red on the
    display with a hint to run the WiFiFirmwareUpdater example, and retried
    every 5 s.
    * receiveUdp() read one datagram per loop(). A loop iteration with redraws is
    often slower than the radar's 100 ms frame period and lwIP keeps only 8
    queued datagrams (dropping new ones), so the display ran several frames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
    [rd03d_giga_receiver.ino]
2026-10-04 Update circuit diagram image in README
2026-10-04 Correct battery voltage in README
    Updated battery voltage specification from 3.3V to 3.7V.
